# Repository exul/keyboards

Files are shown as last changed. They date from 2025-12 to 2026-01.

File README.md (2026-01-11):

# Disclaimer

The files in this repository are meant as inspiration for others who want to build a keyboard from scratch as well. You can build the keyboard yourself with the files provided here, but be aware that it's not beginner friendly. The MCU is soldered directly onto the PCB, the power connection from the PCB to the XIAO needs to be soldered manually, there is no reset button (you'll need to short GND and RST on the exposed XIAO) and the battery is soldered directly onto the PCB as well. When opening the PCB in KiCAD and running the Design Rule Checker it complains about two not connected components, this is because they have to be soldered manually, and I couldn't figure out how to fix this in KiCAD.
The config makes use of custom footprints, meaning that it won't work with the web version of Ergogen.

# My keyboard journey

 I've used ergonomic keyboards for more than 10 years, both prebuilt ones and keyboards I designed and built myself. I've documented my experience so that others can draw some inspiration from it. Depending on what you're planning to do, different chapters might be of interest to you.

1. [How  it all started: The prebuilt keyboards I used and my experience with them](docs/prebuilt_keyboards.md)
2. [Building my own keyboard from scratch](docs/from_scratch.md)

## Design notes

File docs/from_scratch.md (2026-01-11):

# Building a keyboard from scratch

## Building my own keyboard

I'm not going to describe how one builds a keyboard from scratch, other people already did this very well. The most helpful resource on this was [FlatFootFox's Let's Design A Keyboard With Ergogen v4](https://flatfootfox.com/ergogen-introduction/). It's a step-by-step guide that explains how to design a PCB from scratch in Ergogen, design the case and route everything in KiCAD. It doesn't cover reversible PCBs and some other details that I needed, but was an incredibly helpful starting point.

### The design phase

There are a couple of things that I learned from the previous keyboards that I own:

- 40-42 keys is what works best for me
- Low profile because I haven't yet found a good tenting solution and/or the right tenting angle and the flatter the keyboard is the more comfortable it is to type on when it's not tented
- Wireless, but with a decent battery life (I used the Nice!Nano controller)
- Run ZMK, since HRM worked best with the options that ZMK supported (although QMK is catching up)
- Displays will be helpful, especially for debugging when it comes to connectivity (I used Nice!View displays)

With that in mind, I started to design my own keyboard in Ergogen following FlatFootFox's tutorial. Using the online version is very handy, since one can see in real time how the result looks. https://ergogen.xyz/ is the official web based one, but there are also https://ergogen.ceoloide.com/ and https://ergogen.cache.works/ (probably more, but those are the ones I used).

Since I knew nothing about building custom keyboards, I stared simple, just designing one half (the keyboard in the tutorial is not split). I first read all the steps and then started again, this time following along by applying the described steps to my own keyboard. This took quite a bit of time, especially the routing part was hard for me to grasp at first, but after a couple of tries I had a fully routed PCB. It was only the left half, it was not reversible, and it wasn't yet in the exact way I wanted it to be, but it should be functional if I didn't screw-up. I ordered the PCP via https://www.pcbway.com/. This way I could use it to test my design, learn to solder and make sure I have everything covered.

Now that I had the PCB, I wanted to make sure the design fits my hand (that's one of the main reasons why I considered building a keyboard from scratch). Because I knew that I'll have to iterate on the design and that I wanted to print the case myself, I ordered a 3D printer, the Bambu Lab A1 mini. I could have used a service to print the case, but being able to print the case, put some switches in it and test that way was super helpful. But before I started 3D printing, I printed the outlines on paper. This is much faster to get to roughly the correct shape and distribution of the keys. For me especially, the thumb position was tricky. After having an approximation of what I wanted in 2D, I 3D printed the case. I printed *lots* of prototypes until I was satisfied with the result.

I also cut out a rectangle on the PCB to support a bigger battery without making the case thicker. I don't remember where I got the idea from, but after going through my bookmarks, my inspiration probably was the [Lintilla](https://github.com/ctranstrum/lintilla).

Some test prints (sorry for the plastic waste):
A pile of different 3D printed keyboard cases test prints

### Building half of it
In the meantime, the PCB of my left half arrived (actually 5 PCBs since that's the minimal amount you can order). I used a combination of parts that I salvaged from pre-built boards that I had (e.g. Nice!Nano controllers) and parts that I ordered (hot-swap sockets, diodes, etc.). This way I could also learn desoldering components.
Besides the parts for the keyboard, I also needed all the tooling to solder, like the soldering iron, multi-meter (absolutely essential), etc. I started soldering on the balcony since I didn't have a soldering smoke absorber/filter. After the first evening doing so, I ordered a soldering smoke absorber. This was in December and it was roughly 0 degrees Celsius (which is 32 Fahrenheit those weird people who use the imperial unit system - no offense).
After many issues (and even more swear words), I had a working left half of my keyboard. Here's what I learned:

- just try, don't be afraid of breaking things (and make sure you can afford to break things because you're very likely going to break things)
- make sure you solder components with the right orientation (especially diodes, but also the controller ;-))
- have a multimeter to check your soldering (really, without it, it's almost impossible to find issues)
- make sure you have enough time and be patient and keep trying (I made lots of mistakes, but I'm also very stubborn and just kept trying, understanding where the problem could be, narrowing it down, finding it, fixing it)

The left half (non-reversible PCB):
Left half of a split keyboard v1 left only

### Setting up ZMK (for half a keyboard)
When I wrote that I now had a working version, then that's only half the truth (pun intended). I had half a keyboard that made my multimeter beep when I pressed a key, and I've tested each key, but it didn't yet work with a computer. Because now that the hardware is in place, the next important component is firmware, in this case ZMK. What it does is, it translates the signals from the keyboard, like pins are active, into something a computer can understand.
ZMK's documentation is really good, the [Hardware Integration](https://zmk.dev/docs/development/hardware-integration) page describes the main components that are needed for a new keyboard. Another source of information is looking for keyboards that run ZMK as well and are open source. Gitub tags are very helpful to find those. Because there are constantly new features and the formats sometimes change (incl. breaking changes), it's worth looking at some of the most recent examples.
At this point I didn't bother to set up a physical layout that can be used with ZMK studio, more on that later though.
What I didn't like when setting up a keyboard in ZMK were the error messages. Those were a bit hit or miss. Some of them clearly pointed to the config that was the problem, but some of them didn't give me any clear direction of what to look for. As with most problems, I'd recommend getting a very basic version running and then incrementally changing it to your needs.

### Make the PCB reversible
Now that I had a working version of half my keyboard, I wanted to make it reversible. This allows me to order one PBC that I can use for both halves. Just make it work both ways, easy, right? Well, let me tell you that it wasn't easy for me. But once you understand how the keyboard matrix actually works, it becomes mainly a challenge of how to get the routing done. Luckily the footprints I used from Ergogen already supported reversible PCBs, this helped a lot, especially for the sockets and the controller.
I don't have a step-by-step guide to describe how to build a reversible PCB, since a lot will depend on the components that are used. As described above, what helped the most was using footprints (the "building blocks" of the PCB) that are reversible in Ergogen. If the footprints are reversible, then the "Design Rules Checker" in KiCAD can show you what connections you're missing.

### Let's make it more difficult - adding encoders
But why stop there? As part of my research I found boards that had rotary encoders and thought: Nice, those have to be very handy for scrolling or to control the volume. So I decided to add them as well. Which meant I had two more problems:
1. How to wire them (luckily the Nice!Nano has enough pins to support encoders)
2. I wanted to use the EVQWGD001, which are no longer produced and pretty hard to get since they're sold out in most shops

To help with 1., there's a very good description on GitHub: [EVQWGD001-Pinout](https://github.com/rroels/EVQWGD001-Pinout). For two, I can't remember where I bought them, but I was able to find some. I later found out that there's now a very low cost (~ 1USD) DIY version: [MEH01](https://github.com/EverydayErgo/MEH01).

### The first full board
With that I had my first full board:
* 40 keys, 2 encoders
* PCB: reversible, designed in Ergogen and ordered via PCBWay
* Controller: Nice!Nano
* Displays: Nice!View
* 200 mAh battery
* Hotswap Sockets
* Kailh Choc Red switches (50g, linear, choc v1)
* Choc spacing

After a bit more debugging (mistakes during soldering and figuring out how encoders work in ZMK), I finally had my first fully functioning split keyboard that I designed myself.

The first version of the keyboard with EVQWGD001 encoders and Nice!View displays:

An split keyboard with a trackpad in the middle v1 top view

### Using the v1 prototype

I used it for roughly 5 months and then decided that I needed to design another one because:

* I didn't like the look of the displays on the keyboard (I wanted to have them flush with the case, which I wasn't able to do)
* The displays used too much battery (even though they're already a lot better than OLED displays)
* The battery was too small
* I liked the design of the Piantor because it's so clean

That's when I decided to use a dongle. This would allow me to have better battery life (the dongle does the heavy lifting instead of the left half).

I also experimented a lot with tenting solutions:

* integrating a MagSafe magnet into the case and using [phone stands](https://eu.ugreen.com/en-ch/products/ugreen-magsafe-360-adjustable-phone-stand) to tilt the keyboard
* using [camera clamp mounts](https://www.smallrig.com/global/list/Super-Clamp.html) with a [Magnetic Mount Adapts Tripod](https://www.jjc.cc/index/goods/detail.html?id=1336) to tilt the keyboard
* using either version with and without [wrist rests](https://www.fellowes.com/uk/en/catalog/workspace-ergonomics/ergonomic-accessories/details/wrist-rests/UK-9112301)

I wasn't able to find the ideal tenting angle that would feel comfortable, and all of those setups weren't stable enough for me. There's plenty of people reporting that either of these solutions work for them and are rock solid, but they didn't work well for me. Besides the stability problems, I also had issues with my thumb. It started to hurt when using the keyboard at an angle. It felt like the thumb keys were too high and the angle at which I hit them/the movement I had to do with my thumb was putting more strain on my thumb than when the keyboard was flat.

Due to tenting not working for me, I got obsessed with making the keyboard flatter. I accepted that the pronation of my forearms will not be ideal and optimized for the remaining things:
* the split takes care of the ulnar deviation
* a flat keyboard means less wrist extension even when used without wrist rests and without hovering while typing
* lighter switches mean less force is needed to press each switch
* [Ripple Thumb Keycaps](https://github.com/nmunnich/ripple-thumb-keycaps) for the thumbs instead of standard 1.5u keys

Besides the ergo aspects I also optimized some of the technical aspects:
* increased battery life by moving the displays from the keyboard to a dongle
* increased battery life by using a bigger battery
* removing the encoders since I didn't use them much
* switching to Seeed Studio XIAO nRF52840 for the smaller footprint (it's also cheaper)

### Building the v2 prototype - make it flatter

The build process of the v2 was fairly straight forward, since I had an existing design. The main work was to update it to the Seeed XIAO's pinout. But there were two additional challenges with that:

1. The XIAO's footprint didn't work on the latest KiCAD
2. The XIAO footprint is reversible, but puts the routing right below the MCU

The first was an [easy fix](https://github.com/ceoloide/ergogen-footprints/pull/56), for which I provided the changes upstream. The second one was harder. I needed to cut out the part below the MCU from the PCB to be able to make the board flatter. To do so, I needed to move the routing to the side of the MCU. I took me quite some time to figure out how to modify the footprint to support this. The changes are so custom (and ugly) that I only kept them on [my own fork](https://github.com/exul/ergogen-footprints/) of the [ergogen-footprints](https://github.com/ceoloide/ergogen-footprints) repository.

When manufacturing the keyboard, I also decided to go with 1mm thickness instead of the standard 1.6mm. I didn't think about the fact that this could cause issues with the hotswap sockets. Luckily, everything worked it the end.

I also modified the case to have holes for the hotswap sockets and the diodes (I saw this on the [TOTEM](https://github.com/GEIGEIGEIST/TOTEM)). To do this directly in Ergogen I took the socket design that Chad created for his [Charlieflex keyboard](https://github.com/ctranstrum/chuck).

With all those modifications, I was able to get to a key height of 1.5cm and a case height of 0.5cm.

The v2 with the initial version of the case that is just 0.5cm high:

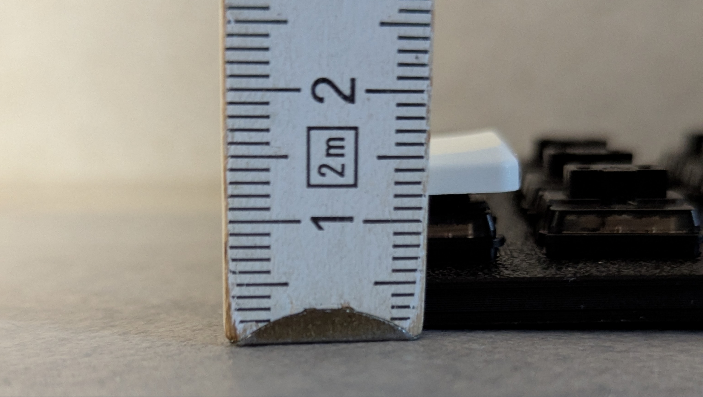
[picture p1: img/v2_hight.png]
A block keyboard with white key caps viewed from the side v2 height


The v2 on my desk with the dongle below the screen and a newer version of the case:

A desk with a white split keyboard on it v2 on desk with dongle

### The second full board
With that I had my second full board:
* 40 keys, no encoders
* PCB: reversible, designed in Ergogen and ordered via PCBWay
* Controller: Seeed Studio XIAO nRF52840
* Dongle: [Prospector](https://github.com/carrefinho/prospector) later switched to [ZMK Dongle Screen YADS (Yet another Dongle Screen)](https://github.com/janpfischer/zmk-dongle-screen), which is heavily inspired by the Prospector
* 500 mAh battery
* Hotswap Sockets
* Ambients Silent Choc Switches: [Nocturnal Low Profile Switches](https://lowprokb.ca/products/ambients-silent-choc-switches?variant=44873446391972) (20g, choc v1) and [Twilight Low Profile Switches](https://lowprokb.ca/products/ambients-silent-choc-switches) (35g, linear, choc v1), I used the Twilight switches after trying both since the Nocturnals where too light for me
* Choc spacing
* [Ripple Thumb Keycaps](https://github.com/nmunnich/ripple-thumb-keycaps) for the thumbs

### Using the v2 prototype

I used this version of the keyboard for about 6 months. But as you might have guessed I identified some issues. Because the board was so thin, the stability of the board was bad. The soldered hotswap sockets caused the PCB to bend slightly and the very thin case didn't help either. I took the thinness of the case unreasonably far, since even though it was just 0.5cm the switches did stick out about 1mm, meaning to have a case that would actually fit the switches would be 0.6cm in height. And while the Ambient Silent Choc Switches where a huge improvement over the reds, I was still looking for better options. I liked the low travel distance of the choc switches, but I still preferred the overall feel of MX switches. It was time to try choc v2 switches as they seemed to be the best mix of the two worlds.
When typing a lot I sometimes hit neighboring keys by accident. I'm not sure if that's because of my big hands or due to the light switches, but I decided to change the spacing to MX spacing, which would also make it easier to find keycaps.

Optimizations for v3:
* choc v2 switches
* slightly adjusted thumb position
* thicker PCB for stability
* MX spacing

### Building the v3 prototype - make it thicker

Since the footprint for the switches that I used was already compatible with choc v2 switches, I didn't have to change much. I printed a couple of cases to test the thumb position and had to adjust the bottom of the case for the v2 choc switches and that was about it.

The v2 on my desk with the dongle below the screen:

A desk with a white split keyboard on it v3 on desk with dongle

### The second full board
With that I had my third full board:
* 40 keys, no encoders
* PCB: reversible, designed in Ergogen and ordered via PCBWay
* Controller: Seeed Studio XIAO nRF52840
* Dongle: [ZMK Dongle Screen YADS (Yet another Dongle Screen)](https://github.com/janpfischer/zmk-dongle-screen)
* 500 mAh battery
* Hotswap Sockets
* Choc v2 Switches: Kailh Deep Sea Silent Mini (50g, linear, choc v2), they felt too heavy and I ordered Kailh Purple Swallowtail Mini (30g, Linear) and Kailh Deep Sea Mini Pink Island Silent (35g, linear)
* MX spacing
* [Ripple Thumb Keycaps](https://github.com/nmunnich/ripple-thumb-keycaps) for the thumbs

The v3 right half with 3x 1 Euro coins stacked up which is ~7mm (this includes the rubber feet):

A desk with a white split keyboard on it v3 on desk with dongle

The v3 bottom side:

The bottom side of a keyboard v3 on desk with dongle

v3 routing:

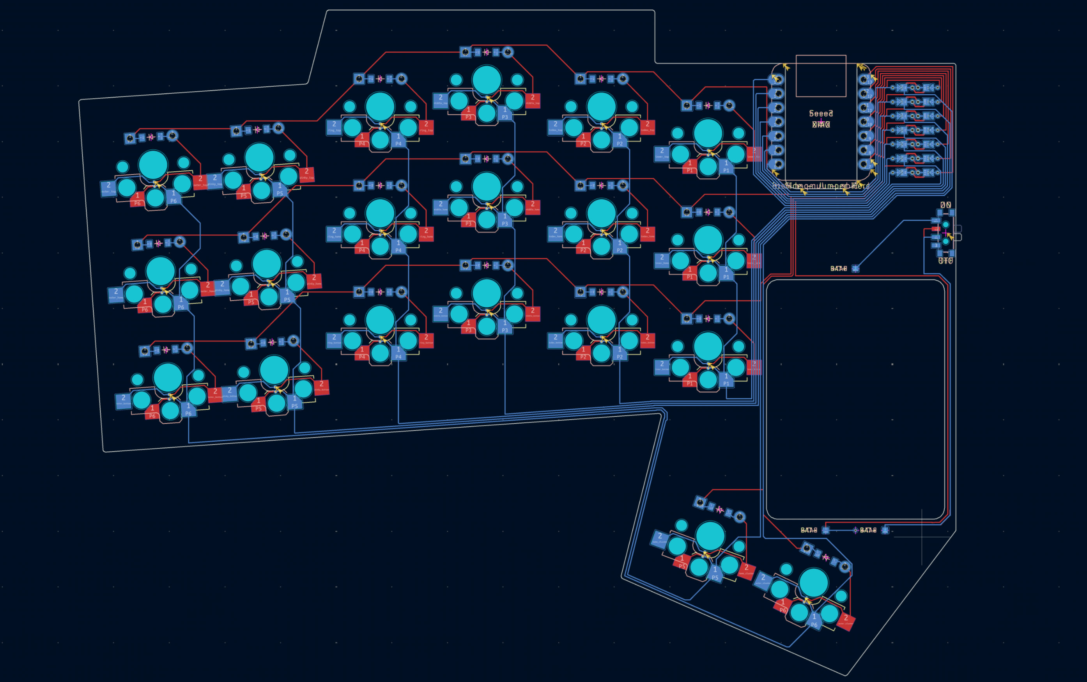
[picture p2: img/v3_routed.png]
Routing of a keyboard v3 on desk with dongle


### Was it worth it?

Yes, absolutely, but also: It depends. My main motivation was and is that it's fun building keyboards and experimenting with layouts. In terms of ergonomics, I'm not sure. There are so many factors and I'm not convinced that smaller keyboards are necessary better. Less physical keys mean less movement of the fingers, but it also means more layers are needed. What I see a lot is that this is done via holding down one of the thumb keys, which can cause issues as well. PSA: Thumbs can get overuse injuries
](https://getreuer.info/posts/keyboards/thumb-ergo/index.html) has a very good description of the involved anatomy even though it's not a scientific paper/study. I do have pain in my right thumb from time to time, but then so does a colleague who is using a standard keyboard. In the end, typing less and moving more is probably what helps most. If you have health problems, ask a doctor and figure out what works for you.

### What's next?

I already have a couple of things that I want to improve/try:

- an angled thumb cluster (like the one that the Moonlander has)
- a track point as part of the keyboard
- use MX switches(?)

But first I'm going to use this version for a while :-).

Besides that, I'm probably going to give [Magic Sturdy](https://github.com/Ikcelaks/keyboard_layouts/blob/main/magic_sturdy/magic_sturdy.md) a try.

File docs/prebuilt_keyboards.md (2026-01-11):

# Prebuilt keyboards

## First steps

My ergonomic keyboard journey started with the Kinesis Advantage 2, many, many years ago (I think around 2015, but I’m not sure). I didn’t have any wrist pain or other health issues, but being a software engineer, I was aware that I’ll sit in front of a computer and type for many more years to come, so why not try something new that can potentially make it more comfortable.
But I didn’t just want to switch to an ergonomic keyboard. I also wanted to learn a new layout. Why, you might ask? I don’t remember. I have a tendency to go all-in on those kind of things. Like, when I switched from Windows to Linux, and I decided to go with Arch Linux and a tiling window manager, but that’s a different story. I knew about Dvorak, I learned about other layouts like Colemak and Workman, but none of them seemed right for me. This was mainly for two reasons: 1. As a software engineer, I often use symbols like brackets, semicolons, etc., and 2. my native language is German, which has umlauts. Eventually I found the [Neo-layout](https://neo-layout.org), which supported everything I needed, symobols, umlauts, and even more. I'm still using the [Neo-layout](https://neo-layout.org) today, even though there are more modern variants of it like [Bone](https://neo-layout.org/Layouts/bone/). This might change, since there are way better options, if you want to learn more, read: https://layouts.wiki/guides/start/intro/.

### Using an ergonomic keyboard for the first time
Using the Kinesis Advantage 2 for the first time was harder than expected. Especially since I started using it with the Neo-layout right away. To not impact my speed at work, I started to only use the Kinesis in the evening when learning the new layout. Due to the different physical keyboards, switching back and forth between my regular keyboard with QUERZ and the Kinesis with Neo was surprisingly easy. Once I got the basics, I started to use the Kinesis when working on hobby projects to get more productive when writing actual code, and eventually, I completely switched to Neo and the Kinesis.

I took my Kinesis Advantage 2 with me when I traveled, but the portability isn't great:

A Kinesis Advantage 2 keyboard with a laptop in front of it Kinesis Advantage 2

### Switching to the ZSA Moonlander
After using the Kinesis for years, I wanted something more compact that I could also take with me in my backpack. Technically, one can do that with the Kinesis too, and I did it a few times, but it’s really bulky. In 2020, ZSA released the [Moonlander](https://www.zsa.io/moonlander), which I bought in 2021. I love the design and the quality. When I initially used it, I missed the key wells that the Kiesis has, but typing was still comfortable, and the thumb cluster that is also used for tenting worked well for my hands. Having the palm rests integrated into the keyboard is great too.

My setup at home with the ZSA Moonlander:
A ZSA Moonlander keyboard in front of a screen ZSA Moonlander

### Experimenting with layouts
Besides the key wells, I also missed the 6 key thumb clusters the Kinesis has. Time to think about my layout again. The main issue I had was that I couldn't have all the modifiers on the thumb cluster. I ended up keeping control and the meta key (a.k.a. Windows key) on the thumb cluster, since those are my most used modifiers (CTRL for shortcuts and the meta key when using my window manager i3). This is the layout I used: https://configure.zsa.io/moonlander/layouts/MJal0/GLZ5R/0/34/. It's from 2020, even though according to the confirmation e-mail, I bought the Moonlander in 2021. I might have started to experiment with layouts even before I bought it to test if it works for me.

### Home row mods
In 2021, I learned about home row mods, and I was excited. Having the modifiers right at my fingertips sounds awesome. My first layout using home row mods looked like this: https://configure.zsa.io/moonlander/layouts/MJal0/EKRjn/0 (just using CTRL). I flashed the firmware, started writing, and it felt very clunky. I had false positives and false negatives, and couldn't really get used to using home row mods. I tried a couple of options, but nothing seemed to work, so I gave up and flashed my old firmware again.

### Home row mods - round 2
In 2023 I decided to try home row mods again (not really sure why). I read the excellent ["A guide to home row mods"](https://precondition.github.io/home-row-mods) and started to experiment with different tapping terms and other options that [Oryx](https://configure.zsa.io/) exposes. I ended up with this layout: https://configure.zsa.io/moonlander/layouts/MJal0/qRXQK/0. This time, home row mods worked well enough that I kept using them, ~~and I still use home row mods today in 2025~~. I switched to [Callum style mods](https://github.com/callum-oakley/qmk_firmware/tree/master/users/callum) in 2026.

## More pre-build keyboards
### Corne
After starting a new job in 2023 where I work both in the office and from home, I initially took my Moonlander to the office and back home every day. And even though the Moonlander is more portable than the Kinesis Advantage, I started looking for a new keyboard that I'd use at home. ZSA just released their [Voyager](https://www.zsa.io/voyager) which seemed ideal, small, fewer keys, low profile (something I wanted to try for a while). But I like to compare different options when buying things I use every day, so I didn't buy it right away. For months, I researched, compared it to the other well known brands like the [Glove80](https://www.moergo.com), the [Kinesis Advantage 360](https://kinesis-ergo.com/keyboards/advantage360/) and many others. Around that time I found the [ErgoMechKeyboards subreddit](https://www.reddit.com/r/ErgoMechKeyboards/) which opened up a whole new world of possibilities. Meaning that it made my decision even harder.

I already reduced the number of keys that I used on my Moonlander, so something like a 42 key keyboard seemed like the right option. Since I was quite new to this and didn't want to solder it myself (I didn't even have a soldering iron at the time), I decided to go with something popular and pre-build and after a short conversation with their fantastic support I ordered a Corne from [KeebMaker](https://keebmaker.com).

I made a couple of mistakes (they're all fully on me and have nothing to do with the service KeebMaker provides):

1. I chose the wireless option, but still went with OLED and displays per key LEDs. I was fully aware that both the OLED displays and the LEDs would drain the battery real quick, but I thought I can use it both wireless and wired (via two USB cables, not via TRRS). Simply because I wanted to have all the options available. The displays and LEDs can be turned off in ZMK and after tweaking the power setting the battery life was ok (2-3 days of full use for the primary half) but I wanted to get at least 1 full week.
2. I didn't take into account that the size of my hands actually matters that much. With both the Kinesis and the Moonlander the thumb clusters "just worked" for me. The most inner thumb key of the Corne was pretty much inaccessible for me. And even the normal thumb keys weren't working well. I was the first time when using a split keyboard that I developed minor pain in my right thumb.

I tried to mitigate the thumb issue by using lighter switches: 35g Kailh Red Pro, the 20g Kailh Choc Light Blue were too light and I had too many accidental triggers. After that I tried different tenting solutions, like using [SmallRig Camps](https://www.smallrig.com/smallrig-multi-functional-crab-shaped-clamp-with-ballhead-magic-arm-2164.html) to mount the keyboard to my desk. Changing my key map to put less stress on my thumbs partially worked, but I didn't like any of the options and went back to my original layout.

Along the way, I also tried to understand the root cause of the thumb issues I had and found Pascal's excellent summary: [PSA: Thumbs can get overuse injuries](https://getreuer.info/posts/keyboards/thumb-ergo/index.html). He uses a [keyboard layout](https://github.com/getreuer/qmk-keymap) where none of the tap holds to switch layers are on the thumb. For me, switching to the symbol layer with a none-dedicated key never properly worked. In the end, I decided to look for a new keyboard with a better thumb cluster position.

Corne:
A corne keyboard Corne keyboard

### Piantor Pro

From my experience with the Corne, I knew that my next keyboard needed to have a thumb cluster that is further towards the center (more to the right for the left hand and vice versa), since I struggled to use the innermost thumb key (the one that is basically under your palm). I also needed at least 3x6 keys, due to my layout having to support German umlauts and even though by now I was fairly comfortable with home row mods, I was still using a dedicated shift key when typing. In addition to that, it should also have a more aggressive pinky stagger. Fairly early in my quest for my next keyboard, I found [the Piantor Pro](https://shop.beekeeb.com/product/pre-soldered-piantor-split-keyboard/) which one can get pre-build (I was still afraid to solder myself). I dismissed it for a couple of weeks, since it doesn't have a display. Having a display is helpful for me to know what layer I'm on, especially when using non-momentary layers, e.g. for gaming. It's also helpful to know which Bluetooth profile I'm currently connected to, but since this keyboard is wired, that wouldn't be a problem. It's not a must-have, but very handy. The next nice to have is ZMK/wireless. For me, home row mods worked much better on ZMK (using a lot of the settings from [urob's zmk-config - Timeless home row mods](https://github.com/urob/zmk-config#timeless-homerow-mods)) than on QMK (even with tweaks like Pascal's [Achordion](https://getreuer.info/posts/keyboards/achordion/index.html)). The low profile of the Corn worked well for me, since I never found comfortable palm rests other than the ones that come with the Moonlander, which are attached to the keyboard and feel well positioned. Long story short, after weeks of research I ended up buying the Piantor Pro, since it was the closest I could get to my ideal setup.
The service that [beekeeb](https://shop.beekeeb.com/) provided was great. I placed my order on July 20th 2024, the keyboard was shipped on August 4th 2024 and arrived on August 9th in Switzerland. Besides the keyboard, the package also contained two USB-C cables (one to connect the two halves and one to connect the keyboard to your device), some spare key cabs and even a few spare switches and some rubber feet with minimal height (very handy). The build quality is outstanding, and the keyboard looks very clean. Again, great experience ordering from a small ergonomic keyboard shop.

This keyboard worked way better for the size of my hands. Having the thumb keys further towards the center meant that I could keep by thumbs in a more natural position when typing. The pinky stagger also made more of a difference than I expected. But of course there were things I didn't like. The main issue was still the position and shape of the thumb keys. One reason I like typing on my Moonlander is that it has big thumbs keys (1.5u) that I can hit well with the whole side of my thumb. When typing on the Piantor I noticed that I hit the thumb keys at an angle due to them being only 1u (the same size as regular keys).

But what now? I already spent hours and hours to find my perfect keyboard, does it even exist? Remember that I said I tend to go all-in on certain things? After being afraid of soldering myself I thought that if I'm going for yet another keyboard, then I'll build it from scratch and so I did.

Pintor Pro:
A Pintor Pro keyboard Pintor Pro keyboard

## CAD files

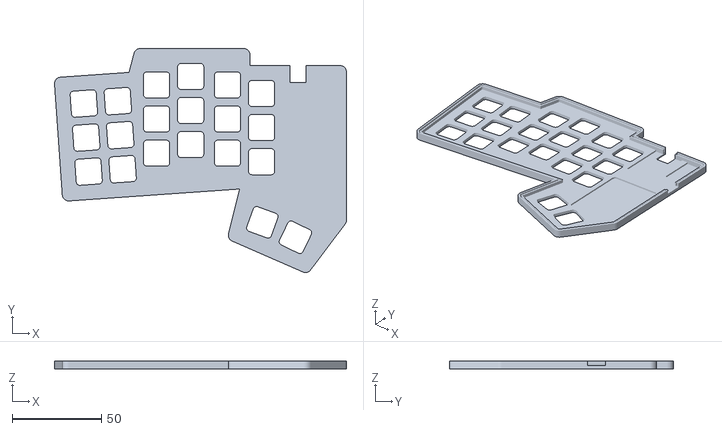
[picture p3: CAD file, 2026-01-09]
prototype/output/cases/right_case_top.stl
163.9 x 125.8 x 4.50

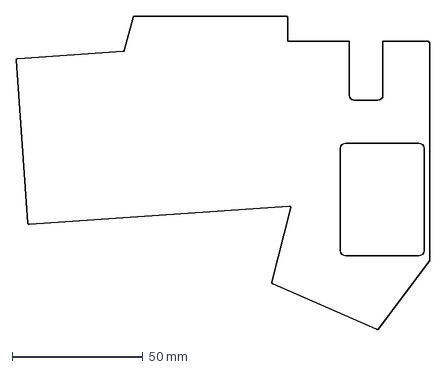
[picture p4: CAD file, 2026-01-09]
prototype/output/outlines/pcb_board.dxf
157.8 x 119.6 mm

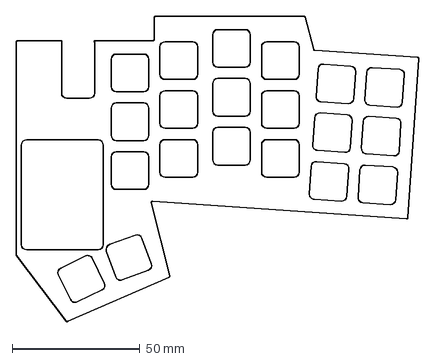
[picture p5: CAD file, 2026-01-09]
prototype/output/outlines/board_preview_right.dxf
157.8 x 119.6 mm

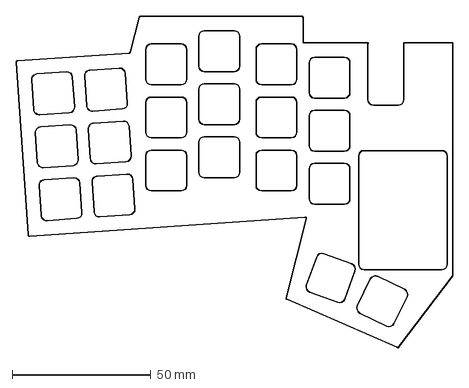
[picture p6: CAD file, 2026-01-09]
prototype/output/outlines/board_preview_left.dxf
157.8 x 119.6 mm

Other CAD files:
prototype/output/cases/left_case_top.stl

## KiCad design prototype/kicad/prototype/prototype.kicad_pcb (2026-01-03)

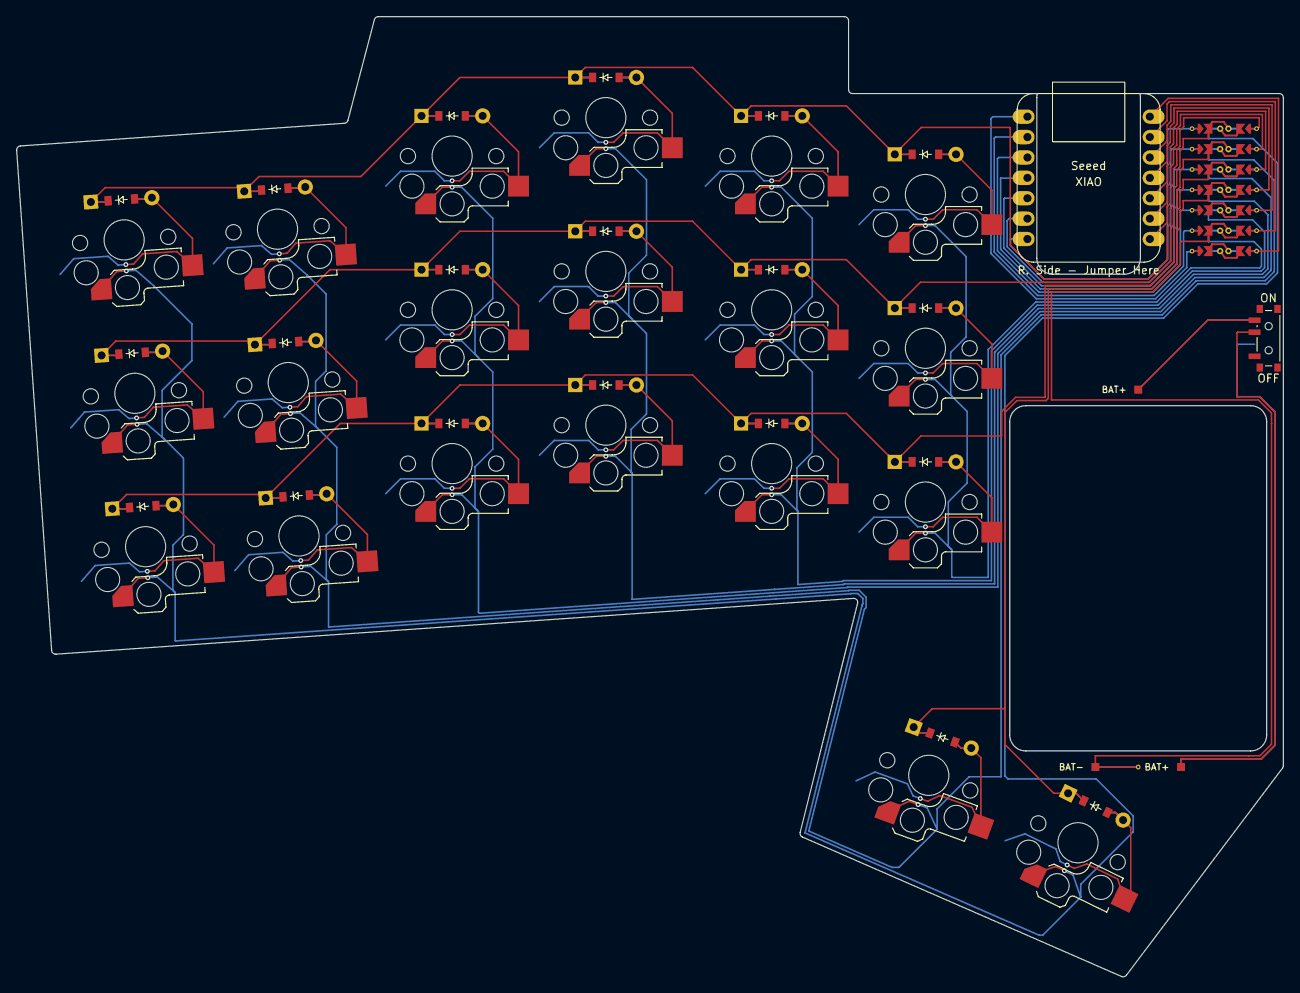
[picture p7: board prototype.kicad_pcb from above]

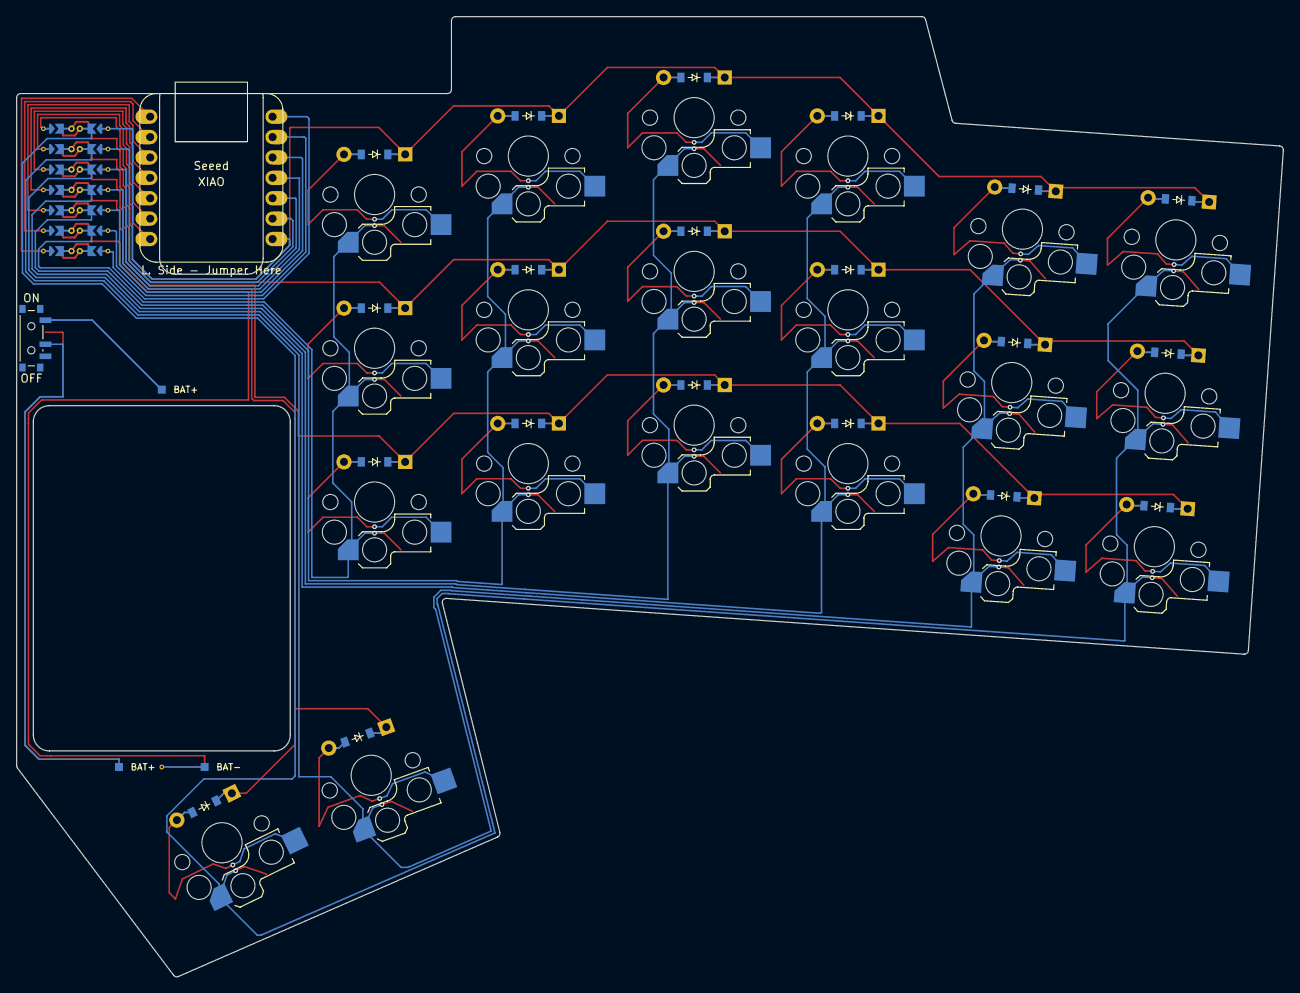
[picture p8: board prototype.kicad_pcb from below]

Board: 2 copper layers, 157.8 x 119.6 mm, 44 parts (20 on the bottom side), 32 nets.

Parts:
D1, D2, D3, D4, D5, D6, D7, D8, D9, D10, D11, D12, D13, D14, D15, D16, D17, D18, D19, D20: ComboDiode
PAD1, PAD2, PAD3: SMDPad
PWR1: power_switch_smd_side
S1, S2, S3, S4, S5, S6, S7, S8, S9, S10, S11, S12, S13, S14, S15, S16, S17, S18, S19, S20: switch_choc_v1_v2

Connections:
BAT+: PAD1.1, PWR1.1, PWR1.3
P1: S16.1, S17.1, S18.1
P2: S13.1, S14.1, S15.1
P3: S10.1, S11.1, S12.1
P4: S7.1, S8.1, S9.1
P5: S4.1, S5.1, S6.1, S19.1
P6: S1.1, S2.1, S3.1, S20.1
P7: D3.1, D6.1, D9.1, D12.1, D15.1, D18.1
P8: D2.1, D5.1, D8.1, D11.1, D14.1, D17.1
P9: D1.1, D4.1, D7.1, D10.1, D13.1, D16.1
P10: D19.1, D20.1
RAW: PAD2.1, PWR1.2
home_cluster: D19.2, S19.2
index_bottom: D13.2, S13.2
index_home: D14.2, S14.2
index_top: D15.2, S15.2
inner_bottom: D16.2, S16.2
inner_home: D17.2, S17.2
inner_top: D18.2, S18.2
middle_bottom: D10.2, S10.2
middle_home: D11.2, S11.2
middle_top: D12.2, S12.2
outer_bottom: D1.2, S1.2
outer_cluster: D20.2, S20.2
outer_home: D2.2, S2.2
outer_top: D3.2, S3.2
pinky_bottom: D4.2, S4.2
pinky_home: D5.2, S5.2
pinky_top: D6.2, S6.2
ring_bottom: D7.2, S7.2
ring_home: D8.2, S8.2
ring_top: D9.2, S9.2

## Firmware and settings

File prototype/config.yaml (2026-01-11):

# This config makes use of custom footprints that only work with a locally run version of Ergogen and will not work with the web version of Ergogen.
# If you're looking for a config that you can modify in Ergogen web, there's a version that only uses built-in footprints here (but it won't generate a working PCB since some footprints aren't available at all in Ergogen, and for some, the pinout doesn't match with the custom footprint): https://gist.github.com/exul/7b3d09b1ea04f9b52bd185b6bea1cb12
units:
  # choc v1 switches
  $default_width: U
  $default_height: U

  # space between columns (spread)
  ks: U+0.1

  # space between rows (padding)
  kp: U+0.1

  # min. distance between copper and the edge of the board
  battery_switch_edge_clearance: 0.4

  # switch dimensions - source: http://www.kailh.com/en/Products/Ks/CS/755.html
  switch_width: 14
  switch_height: 14
  switch_hole_extra_spacing: 0.7

  # mcu (Seeed Studio XIAO nRF52840) dimensions - source: https://www.seeedstudio.com/Seeed-XIAO-BLE-nRF52840-p-5201.html
  mcu_width: 17.5
  mcu_length: 21
  mcu_width_clerance: 1
  mcu_length_clerance: 3
  mcu_to_key_clearance: 2

  # cutout on the pcb to mount the mcu face down
  mcu_pcb_cutout_width: 12.9
  mcu_pcb_cutout_length: mcu_length + mcu_length_clerance

  # height/width of the battery switch: source: https://cdn.shopify.com/s/files/1/0618/5674/3655/files/ALPS-SSSS811101.pdf?v=1670451309
  battery_switch_height: 4
  battery_switch_width: 2.9
  battery_switch_length: 8
  battery_switch_cutout_width_tolerance: 2
  battery_switch_cutout_depth_tolerance: 6

  # width of the reset switch: https://cdn.shopify.com/s/files/1/0618/5674/3655/files/PANASONIC-EVQPUC02K.pdf?v=1670451309
  reset_switch_width: 3.5

  # thumb key positons and rotation settings - source: https://github.com/nmunnich/ripple-thumb-keycaps?tab=readme-ov-file#design-guidelines
  thumb_middle_x_offset: 17
  thumb_middle_y_offset: 0
  thumb_middle_rotation: -7
  thumb_outer_x_offset: 37
  thumb_outer_y_offset: 4
  thumb_outer_rotation: -13

  # extra space between index and middle finger
  index_spread: ks+1.5

  # move ring column up by this number to have a stagger for the pinky and outer column
  pinky_stagger: 0.4 kp

  # extra space between pinky and index finger
  pinky_spread: ks+0.5

  # rotete pinky and outer column by this number (minus for counter clock wise)
  pinky_splay: -4

  # move middle column up by this number to have a stagger for the ring column
  ring_stagger: 0.25kp

  # move index column down by this number to have a stagger for the middle column
  middle_stagger: 0.25kp

  # move inner column down by this number to have a stagger for the index column
  index_stagger: 0.25kp

  # shift the whole thumb cluster along the x axis
  thumb_x_shift: 3

  # shift the whole thumb cluster along the y axis
  thumb_y_shift: 35

  # rotate the whole thumb cluster
  thumb_cluster_rotate: -13

  # size of the mcu area
  mcu_area_width: 35

  # space between the pcb and the wall of the case
  pcb_to_case_wall_tolerance: 0.5

  # thickness of the wall
  wall_thickness: 1

  # thickness of the bottom case
  bottom_plate_thickness: 1

  # thickness of the top plate
  top_plate_thickness: 2

  # space between the bottom and the top plate of the case
  internal_distance_between_plates: 1.5

  # distance between the nice view's bottom edge and the GND via
  via_oled_GND_clearance: 3

  # battery cutout
  battery_cutout_width: 32
  battery_cutout_height: 43
  battery_cutout_x_shift_matrix_inner_bottom: 26.5
  battery_cutout_y_shift_matrix_inner_bottom: -9.5
  battery_cutout_rotation: 0

  # usb-c cutout
  usbc_height: internal_distance_between_plates # use 3.3, once nice nano position on PCB is fixed
  usbc_width: 9 # change to 9, once nice nano position on PCB is fixed
  usbc_length: 9
  usbc_jut: 2 # number of milimeters the usbc plag stucks out from the PCB

  # added thickness to the bottom to make the case more stable
  stability_height: 1

  # snap tolerance, extra space between the double wall from the top plate and the single wall of the bottom place, the smaller the tighter the fit of the snap is
  snap_tolerance: 0.0

  # how wide the empty space between the two snap walls is, this is the slot between the double wall on the bottom case
  snap_slot_width: 0.8+snap_tolerance/2
  # how wide the middle wall is, this is the wall of the bottom case, that goes into the snap slof of the top case
  snap_middle_wall_width: snap_slot_width-snap_tolerance/2
  # this ts the width of the inner wall of the double wall on the top case
  inner_snap_wall_width: snap_slot_width
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

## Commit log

2024-12-01 add output
    first working version
    [battery_cutout.dxf, board.dxf, board.kicad_pcb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]
2025-05-23 switch to Seeed Xiao
2025-06-16 prototype thin version
2025-06-27 prototype thin version built
2025-12-26 improve case
2025-12-26 add kicad files
    [board.kicad_pcb, prototype.kicad_pcb, prototypenightlz.kicad_pcb]
2025-12-26 new footprint folder
2025-12-26 latest pcb
    [board.kicad_pcb, prototype.kicad_pcb, prototype.kicad_sch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]
2026-01-01 update case
2026-01-02 fix right case bottom
    [config.yaml]
2026-01-03 add latest pcb
    [prototype.kicad_pcb]
2026-01-08 minor case fix
2026-01-09 add output files
    [board_preview_left.dxf, board_preview_right.dxf, left_case_top.stl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]
